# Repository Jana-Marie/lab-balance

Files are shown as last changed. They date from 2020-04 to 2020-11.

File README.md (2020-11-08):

# lab-balance

This project aims to replace the electronics contained within a [cheap scale from AliExpress](https://aliexpress.com/item/33024586342.html) to archive a higher resolution and hackability. Furthermore I need a scale which does not turn off after 30 seconds of use!

The goal is not met so far, as the accuracy of the load cell is not sufficient for this task. It can be replaced with a higher end model.

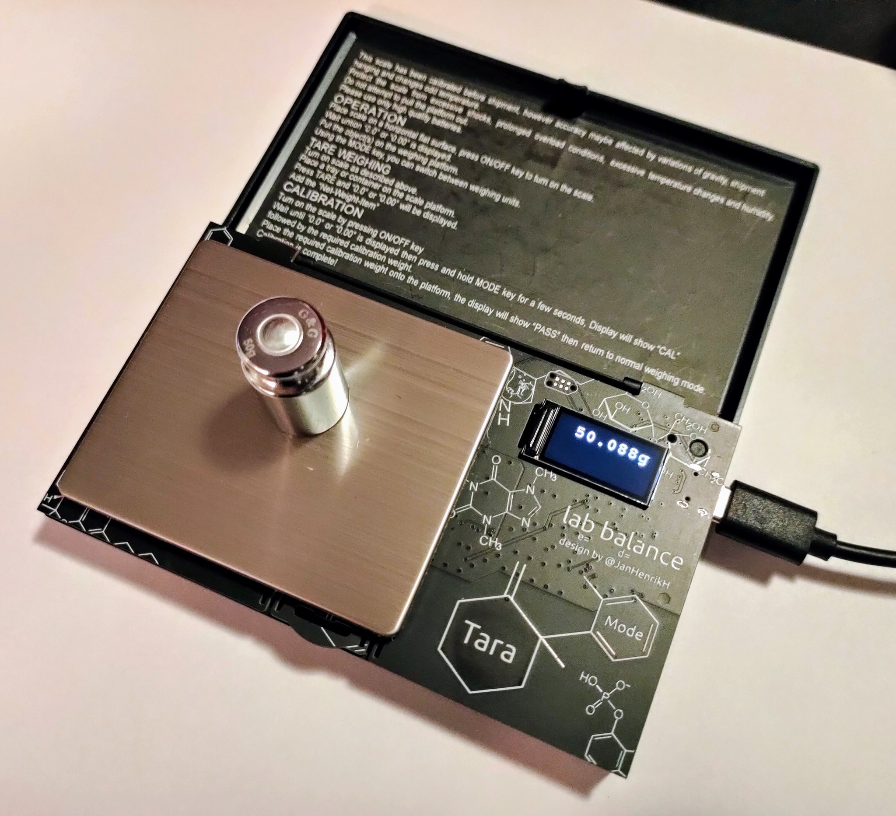
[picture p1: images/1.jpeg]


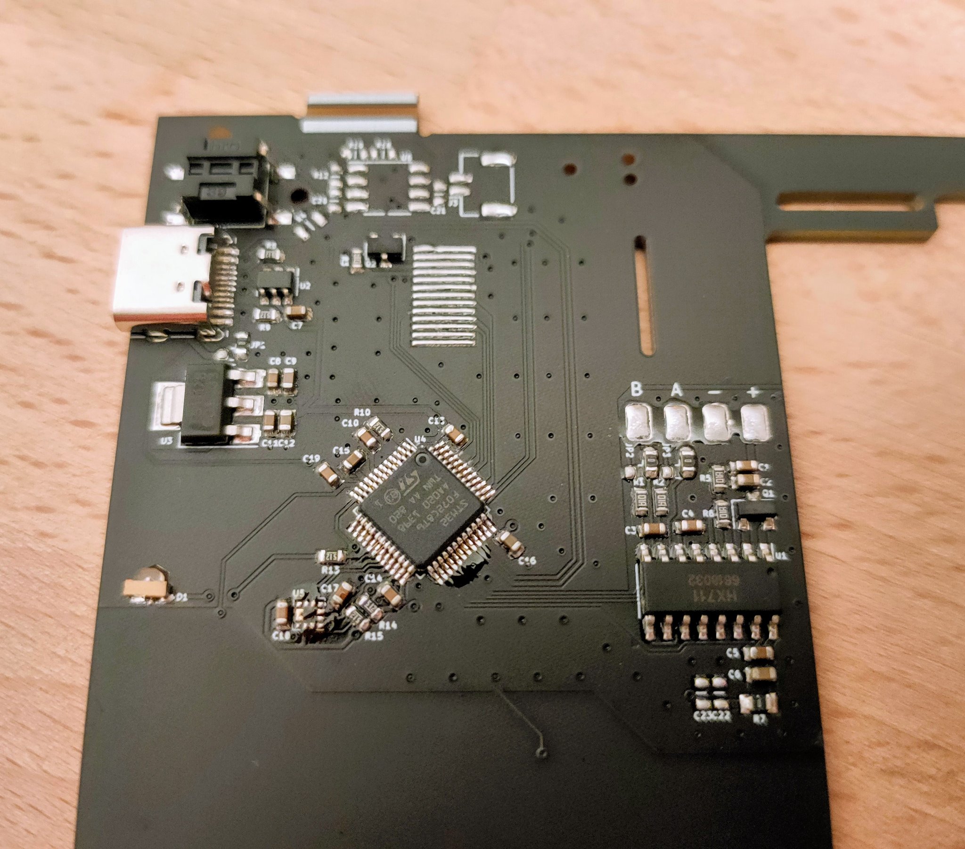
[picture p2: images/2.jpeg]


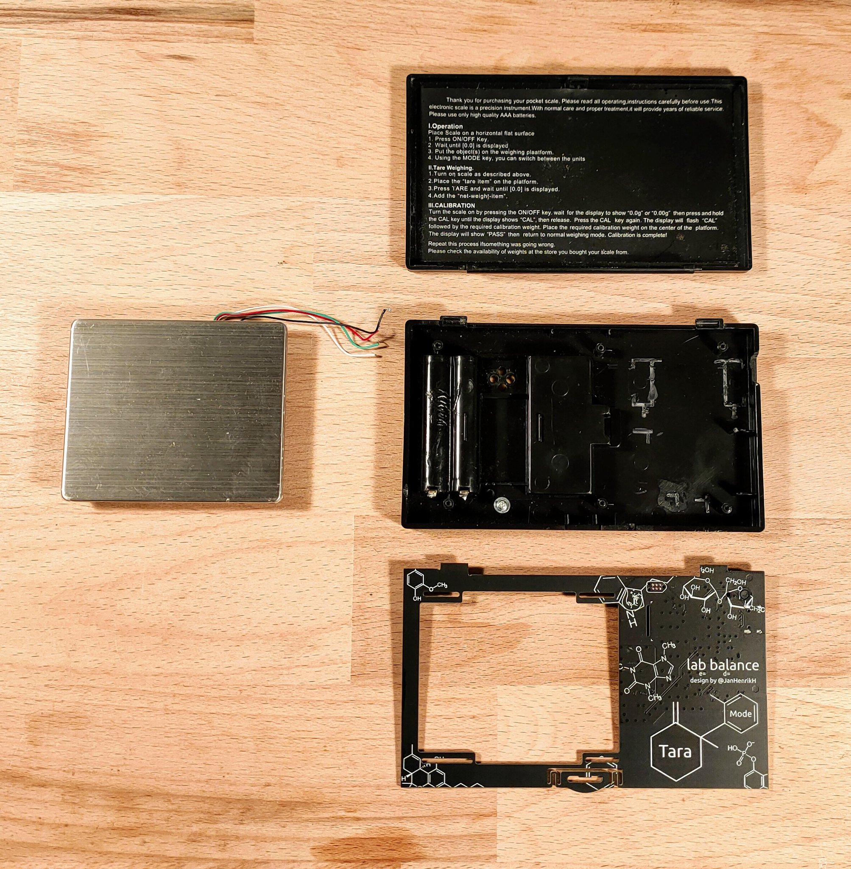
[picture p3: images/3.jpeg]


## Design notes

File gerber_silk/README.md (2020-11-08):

# note: There is a bug in the gerber files. The display has to be bodged in this version, order at your own risk!

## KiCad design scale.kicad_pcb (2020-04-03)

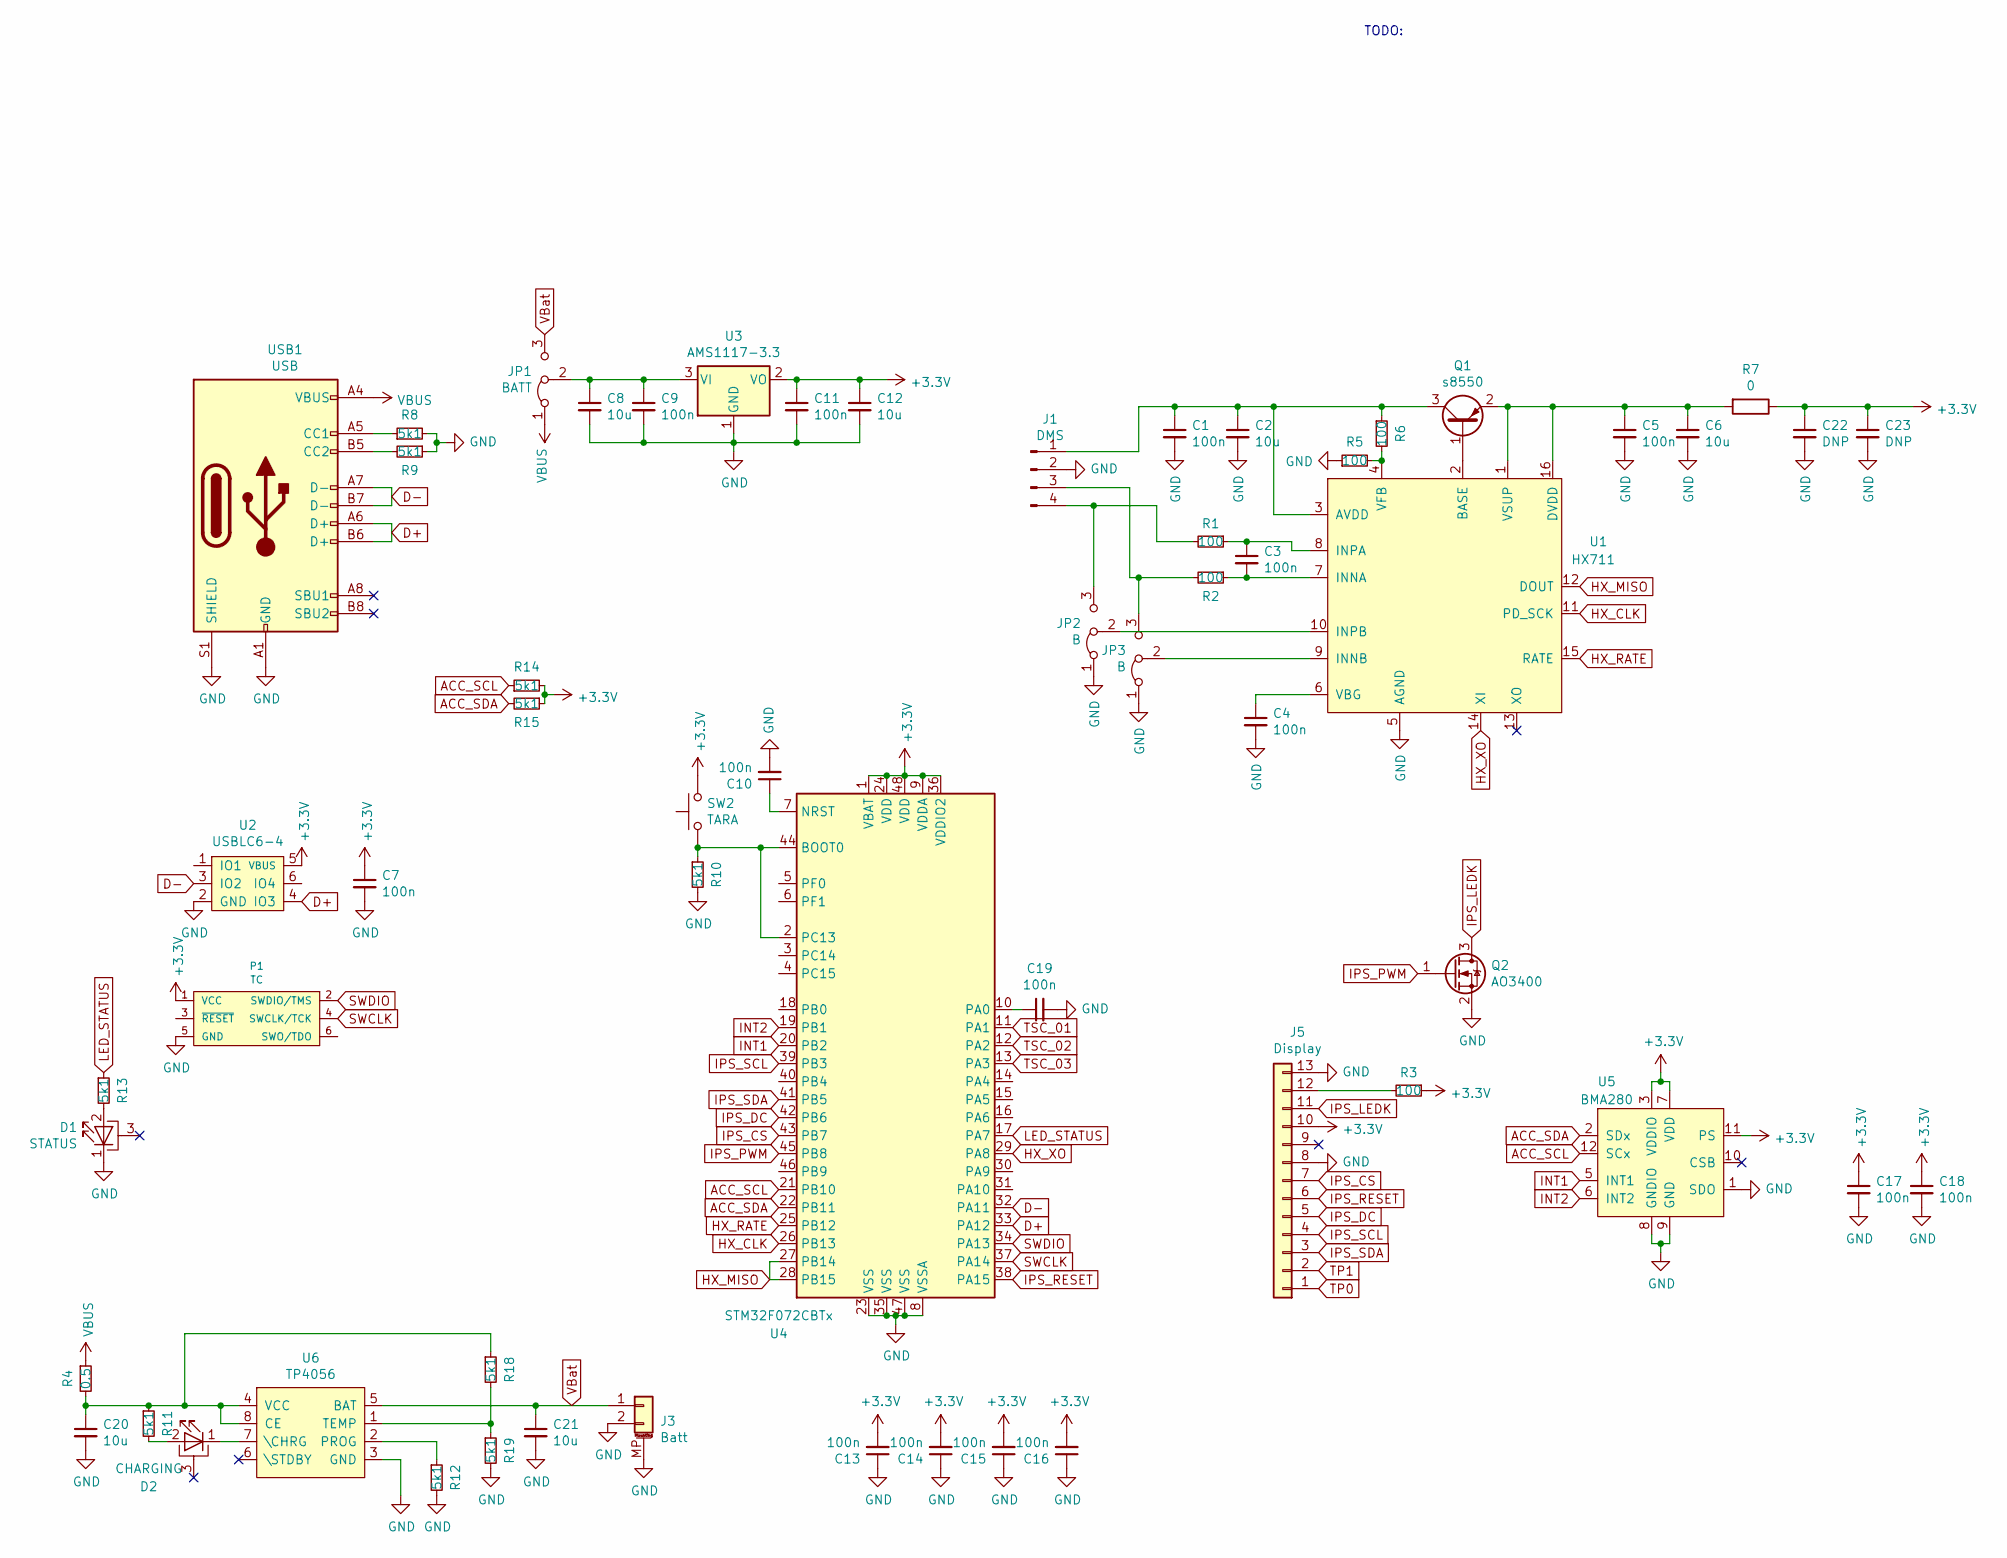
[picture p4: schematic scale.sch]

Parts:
C1, C3, C4, C5, C7, C9, C10, C11, C13, C14, C15, C16, C17, C18, C19: 100n; C_0603
C2, C6, C8, C12, C20, C21: 10u; C_0603
C22, C23: DNP; C_0603
D1: STATUS; BL-HUB34E-AV-TRB
D2: CHARGING; BL-HUB34E-AV-TRB
J1: DMS; 04_pads
J3: Batt; JST_GH_SM02B-GHS-TB_1x02-1MP_P1.25mm_Horizontal
J5: Display; 0.96IPS
JP1: BATT; J_0603_90
JP2, JP3: B; J_0603_90
P1: TC; TC2030
Q1: s8550; SOT-23
Q2: AO3400; SOT-23
R1, R2, R3, R5, R6: 100; R_0603
R4: 0.5; R_0805
R7: 0; R_0805
R8, R9, R10, R11, R12, R13, R14, R15, R18, R19: 5k1; R_0603
SW2: TARA; K2-1102DP-C4SW-04
U1: HX711; SOIC-16_3.9x9.9mm_P1.27mm
U2: USBLC6-4; SOT-23-6
U3: AMS1117-3.3; SOT-223-3_TabPin2
U4: STM32F072CBTx; LQFP-48_7x7mm_P0.5mm
U5: BMA280; LGA-12_2x2mm_P0.5mm
U6: TP4056; SOP-8_3.9x4.9mm_P1.27mm
USB1: USB; USB-C 16Pin

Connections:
+3V3: C7.1, C11.1, C12.1, C13.2, C14.2, C15.2, C16.2, C17.1, C18.1, C22.1, C23.1, J5.10, P1.1 (VCC), R3.1, R7.1, R14.2, R15.1, SW2.2, U2.5 (VBUS), U3.2 (VO), U4.1 (VBAT), U4.9 (VDDA), U4.24 (VDD), U4.36 (VDDIO2), U4.48 (VDD), U5.3 (VDDIO), U5.7 (VDD), U5.11 (PS)
ACC_SCL: R14.1, U4.21 (PB10), U5.12 (SCx)
ACC_SDA: R15.2, U4.22 (PB11), U5.2 (SDx)
D+: U2.4 (IO3), U4.33 (PA12), USB1.A6 (D+), USB1.B6 (D+)
D-: U2.3 (IO2), U4.32 (PA11), USB1.A7 (D-), USB1.B7 (D-)
GND: C1.2, C2.2, C4.2, C5.2, C6.2, C7.2, C8.2, C9.2, C10.2, C11.2, C12.2, C13.1, C14.1, C15.1, C16.1, C17.2, C18.2, C19.2, C20.2, C21.2, C22.2, C23.2, D1.1 (K), J1.2, J3.2, J3.MP (MountPin), J5.8, J5.13, JP2.1 (A), JP3.1 (A), P1.5 (GND), Q2.2 (S), R5.1, R8.2, R9.1, R10.2, R12.2, R19.2, U1.5 (AGND), U2.2 (GND), U3.1 (GND), U4.8 (VSSA), U4.23 (VSS), U4.35 (VSS), U4.47 (VSS), U5.1 (SDO), U5.8 (GNDIO), U5.9 (GND), U6.3 (GND), USB1.A1 (GND), USB1.A12 (GND), USB1.B1 (GND), USB1.B12 (GND), USB1.S1 (SHIELD)
HX_CLK: U1.11 (PD_SCK), U4.26 (PB13)
HX_MISO: U1.12 (DOUT), U4.27 (PB14), U4.28 (PB15)
HX_RATE: U1.15 (RATE), U4.25 (PB12)
HX_XO: U1.14 (XI), U4.29 (PA8)
INT1: U4.20 (PB2), U5.5 (INT1)
INT2: U4.19 (PB1), U5.6 (INT2)
IPS_CS: J5.7, U4.43 (PB7)
IPS_DC: J5.5, U4.42 (PB6)
IPS_LEDK: J5.11, Q2.3 (D)
IPS_PWM: Q2.1 (G), U4.45 (PB8)
IPS_RESET: J5.6, U4.38 (PA15)
IPS_SCL: J5.4, U4.39 (PB3)
IPS_SDA: J5.3, U4.41 (PB5)
LED_STATUS: R13.1, U4.17 (PA7)
unnamed: C1.1, C2.1, J1.1, Q1.3 (C), R6.1, U1.3 (AVDD)
unnamed: C3.1, R1.1, U1.8 (INPA)
unnamed: C3.2, R2.1, U1.7 (INNA)
unnamed: C4.1, U1.6 (VBG)
unnamed: C5.1, C6.1, Q1.2 (E), R7.2, U1.1 (VSUP), U1.16 (DVDD)
unnamed: C8.1, C9.1, JP1.2 (C), U3.3 (VI)
unnamed: C10.1, U4.7 (NRST)
unnamed: C19.1, U4.10 (PA0)
unnamed: C20.1, R4.2, R11.1, R18.1, U6.4 (VCC), U6.8 (CE)
unnamed: D1.2 (A), R13.2
unnamed: D2.1 (K), U6.7 (\CHRG)
unnamed: D2.2 (A), R11.2
unnamed: J1.3, JP3.3 (B), R2.2
unnamed: J1.4, JP2.3 (B), R1.2
unnamed: J5.12, R3.2
unnamed: JP2.2 (C), U1.10 (INPB)
unnamed: JP3.2 (C), U1.9 (INNB)
unnamed: Q1.1 (B), U1.2 (BASE)
unnamed: R5.2, R6.2, U1.4 (VFB)
unnamed: R8.1, USB1.A5 (CC1)
unnamed: R9.2, USB1.B5 (CC2)
unnamed: R10.1, SW2.1, U4.2 (PC13), U4.44 (BOOT0)
unnamed: R12.1, U6.2 (PROG)
unnamed: R18.2, R19.1, U6.1 (TEMP)
SWCLK: P1.4 (SWCLK/TCK), U4.37 (PA14)
SWDIO: P1.2 (SWDIO/TMS), U4.34 (PA13)
TP0: J5.1
TP1: J5.2
TSC_01: U4.11 (PA1)
TSC_02: U4.12 (PA2)
TSC_03: U4.13 (PA3)
VBUS: JP1.1 (A), R4.1, USB1.A4 (VBUS), USB1.A9 (VBUS), USB1.B4 (VBUS), USB1.B9 (VBUS)
VBat: C21.1, J3.1, JP1.3 (B), U6.5 (BAT)

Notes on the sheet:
TODO:

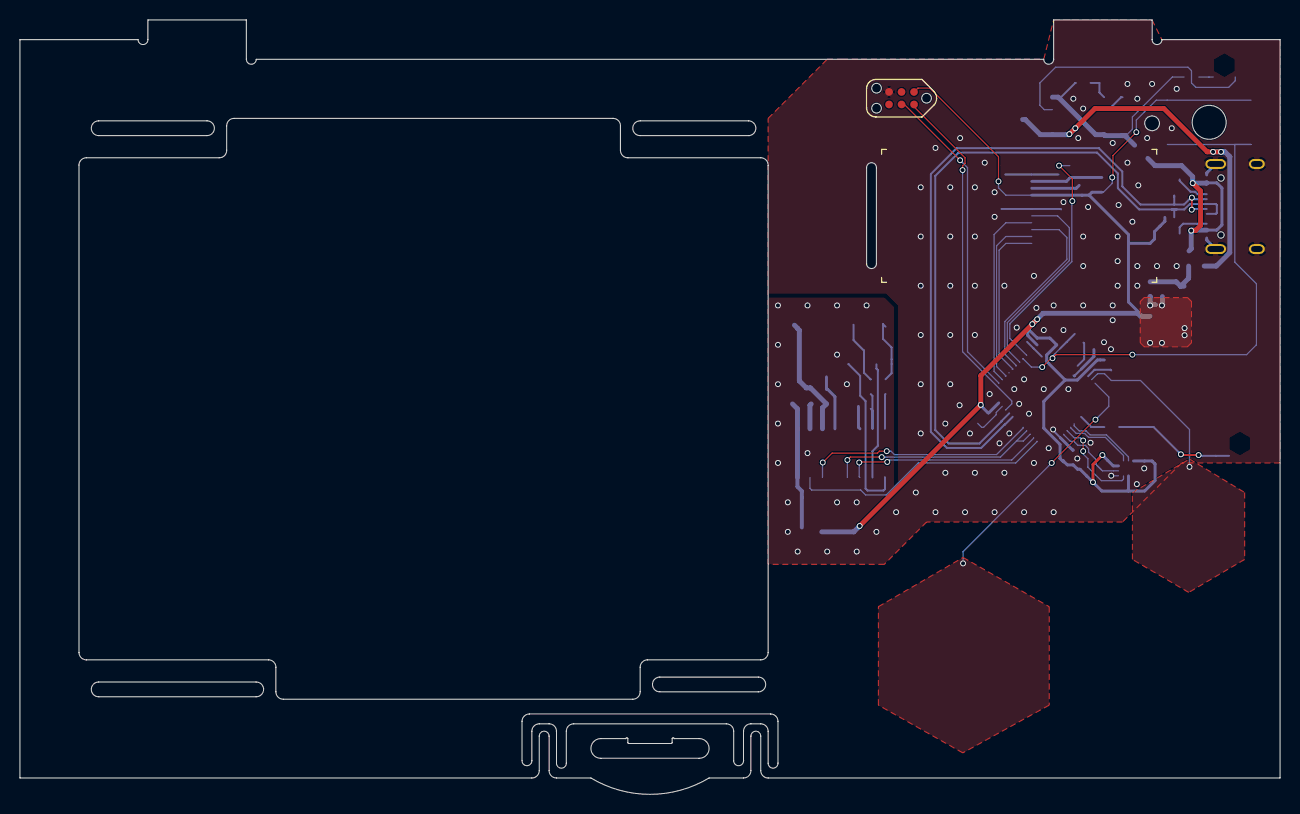
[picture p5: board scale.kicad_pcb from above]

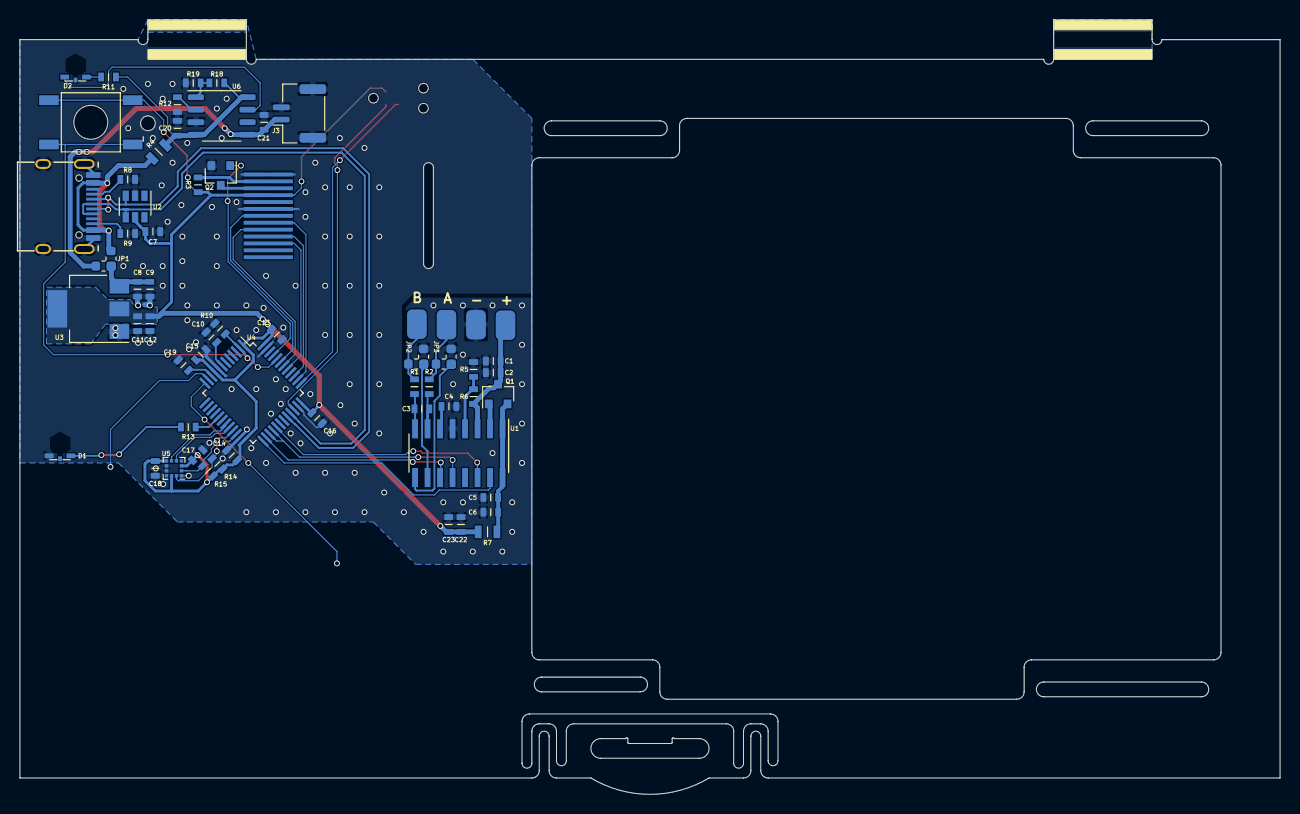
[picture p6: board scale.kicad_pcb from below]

Board: 2 copper layers, 128.0 x 78.7 mm, 59 parts (57 on the bottom side), 48 nets.

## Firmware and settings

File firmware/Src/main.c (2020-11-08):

#include "main.h"
#include "graphics.h"
#include "math.h"
#include "stdlib.h"
#include <stdio.h>
#include "image_header.h"

//#define ENABLE_CAL
//#define ENABLESERIAL

#define HX_GAIN_128 25
#define HX_GAIN_64  27
#define HX_GAIN_32  26
#define MULTIPLIER (72000000/4000000)

#define DATAFILT 0.99f

#define FLASH_ADDR 0x0800e400

I2C_HandleTypeDef hi2c2;

SPI_HandleTypeDef hspi1;
DMA_HandleTypeDef hdma_spi1_tx;

TIM_HandleTypeDef htim1;
TIM_HandleTypeDef htim16;
TIM_HandleTypeDef htim3;

TSC_HandleTypeDef htsc;
TSC_IOConfigTypeDef IoConfig;

USBD_HandleTypeDef USBD_Device;

void SystemClock_Config(void);
static void MX_GPIO_Init(void);
static void MX_DMA_Init(void);
static void MX_I2C2_Init(void);
static void MX_SPI1_Init(void);
static void MX_TIM1_Init(void);
static void MX_TIM16_Init(void);
static void MX_TSC_Init(void);
static void TIM3_Init();

void HX_Get_Value(uint8_t gain);
void HX_Delay(uint32_t u);
void write_tara_bar(uint8_t pos);
void clear_tara_bar(void);
void write_cal_flash(float cal);
void USB_printfloat(float _buf);

struct HX711_t{
  int32_t raw_data;
  int32_t raw_data_avg;
  int32_t delta;
  float weight_g;
  int32_t pcs;
  uint8_t gain;
  uint8_t rate;
  uint8_t clock;
  uint8_t is_stable;
} HX711 = {.gain = HX_GAIN_128};

struct cal_t{
  float g_50;
  float g_0;
  float g_cal;
  uint8_t tara_active;
  uint8_t tara_pcs_active;
  float pcs_cal;
} cal = {.g_cal = 50.093f, .g_50 = -701550.0f, .g_0 = -138500.0f, .tara_active = 1, .pcs_cal = 1.0f};
//50.093

struct touch_t{
  uint8_t button[2];
  uint16_t offset[2];
  uint16_t value[2];
  uint8_t idx_bank;
  uint8_t mode;
  uint8_t new_mode;
} t = {.new_mode = 1};

extern struct IPS_t IPS;

uint32_t start = 0;
uint32_t _ms;

extern uint8_t UserTxBuffer[APP_TX_DATA_SIZE];/* Received Data over UART (CDC interface) are stored in this buffer */
uint32_t sendDataUSB;

int main(void)
{
  HAL_Init();
  SystemClock_Config();

  MX_GPIO_Init();
  MX_DMA_Init();
  MX_I2C2_Init();
  MX_SPI1_Init();
  MX_TIM1_Init();
  MX_TIM16_Init();
  MX_TSC_Init();
  TIM3_Init();

  HAL_GPIO_WritePin(GPIOB,HX_CLK_Pin,0);

  IPS.backlight = 999;
  IPS.update_time = 20;

  #ifdef ENABLE_CAL
  cal.g_50 = *((float *) FLASH_ADDR);
  #endif

  IPS_Init();
  HAL_TIM_Base_Start(&htim16);
  HAL_TIM_PWM_Start(&htim16, TIM_CHANNEL_1);
  __HAL_TIM_SET_COMPARE(&htim16, TIM_CHANNEL_1, IPS.backlight);
  IPS_Clear(BLACK);
  IPS.update = HAL_GetTick();

  HAL_TSC_Start_IT(&htsc);

  HAL_TIM_Base_Start(&htim1);
  HAL_TIM_PWM_Start(&htim1, TIM_CHANNEL_1);
  __HAL_TIM_SET_COMPARE(&htim1, TIM_CHANNEL_1, 0);

  #ifdef ENABLESERIAL
      //start USB CDC
      USBD_Init(&USBD_Device, &VCP_Desc, 0);
      USBD_RegisterClass(&USBD_Device, &USBD_CDC);
      USBD_CDC_RegisterInterface(&USBD_Device, &USBD_CDC_fops);
      HAL_TIM_Base_Start_IT(&htim3);
      USBD_Start(&USBD_Device);
  #endif

  while (1)
  {
    if(t.button[1]) {
      cal.tara_active = 1;
      uint8_t cnt = 0;
      while (t.button[1]){
        if(cnt < 200) cnt++;
        HAL_Delay(2);
      }
      if(cnt >= 200){
        if(t.mode == 2){
        #ifdef ENABLE_CAL
          write_cal_flash(cal.g_50);
          HAL_NVIC_SystemReset();
        #endif
        } else {
         cal.tara_pcs_active = 1;
        }
      cal.tara_active = 0;
      }
    }

    if(t.button[0]) {
      while(t.button[0]) {
        HAL_Delay(1);
      }
      t.mode++;
      t.mode = t.mode % 3;
      t.new_mode = 1;
    }

    if(cal.tara_active && t.mode != 2){
      if(abs(HX711.delta) < 30) cal.tara_active++;
      else cal.tara_active = 1;
      write_tara_bar(cal.tara_active);
      if(cal.tara_active > 20){
        cal.g_0 = HX711.raw_data_avg;
        cal.tara_active = 0;
        clear_tara_bar();
      }
    } else if(cal.tara_active && t.mode == 2){
      if(abs(HX711.delta) < 30) cal.tara_active++;
      else cal.tara_active = 1;
      write_tara_bar(cal.tara_active);
      if(cal.tara_active > 20) {
        cal.g_50 = HX711.raw_data_avg;
        cal.tara_active = 0;
        clear_tara_bar();
      }
    }

    if (cal.tara_pcs_active){
      cal.pcs_cal = HX711.weight_g;
      cal.tara_pcs_active = 0;
      for(int i = 0; i <= 20; i++){
        write_tara_bar(i);
      }
      clear_tara_bar();
    }

    if(!HAL_GPIO_ReadPin(GPIOB,HX_INT_Pin)){
      HX_Get_Value(HX711.gain);
      HAL_GPIO_TogglePin(GPIOA, LED_Pin);
      _ms = HAL_GetTick()-start;
      start = HAL_GetTick();

      if(abs(HX711.delta) <= 2 && (int)((HX711.weight_g-(int)HX711.weight_g)*1000.0f) == 0){
        cal.g_0 -= HX711.delta;
      } else if(abs(HX711.delta) <= 2) {
        cal.g_0 -= HX711.delta;
        cal.g_50 -= HX711.delta;
      }

    } else {
      HAL_Delay(1);
      HAL_GPIO_WritePin(GPIOB,HX_SPS_Pin, HX711.rate);
    }

    if(HAL_GetTick() + IPS.update_time > IPS.update){
      if(HX711.weight_g > -99.9 && HX711.weight_g < 99.9){
        if(t.mode == 0){
          sprintf(IPS.buf,"%c%02d.%03dg", HX711.weight_g >= -0.001 ? ' ' : '-' , abs((int)HX711.weight_g), abs((int)((HX711.weight_g-(int)HX711.weight_g)*1000.0f)));
          IPS_DrawString_Buf(0, 0, IPS.buf, 8, &Font24, BLACK, WHITE);
          IPS_WriteBuf(10,45);
        } else if (t.mode == 1){
          sprintf(IPS.buf,"%c%04dpcs", HX711.weight_g >= -0.001 ? ' ' : '-' , abs((int)roundf(HX711.weight_g / cal.pcs_cal)));
          IPS_DrawString_Buf(0, 0, IPS.buf, 8, &Font24, BLACK, WHITE);
          IPS_WriteBuf(10,45);
        } else if (t.mode == 2){
          sprintf(IPS.buf,"%07d", HX711.raw_data_avg);
          IPS_DrawString_Buf(0, 0, IPS.buf, 8, &Font24, BLACK, WHITE);
          IPS_WriteBuf(10,45);
        }
      } else {
        sprintf(IPS.buf,"  max!  ");
        IPS_DrawString_Buf(0, 0, IPS.buf, 8, &Font24, BLACK, WHITE);
        IPS_WriteBuf(10,45);
      }
      HAL_Delay(4);
      if(t.new_mode == 1){
        if      (t.mode == 0) IPS_WriteBitmap(5 , 5, gram, 32, 20);
        else if (t.mode == 1) IPS_WriteBitmap(5 , 5, cnt, 32, 20);
        else if (t.mode == 2) IPS_WriteBitmap(5 , 5, cal_n, 32, 20);
        t.new_mode = 0;
      } else {
        IPS_WriteBitmap(116, 8, HX711.is_stable == 1 ? tara_green : tara_red, 32, 20);
      }
      IPS.update = HAL_GetTick();
    }
    #ifdef ENABLESERIAL
      // send temperature via USB CDC
      USB_printfloat(HX711.weight_g);
    #endif
  }
}

/* ~~~~~~~~~~~~~~~~~~~~~~~~~~~~~~~~~~~~~~~~~~~~~~~~~~~~~~~~~~~~~~~~~~~~~~~~~~~*/

void HX_Get_Value(uint8_t gain) {

  int32_t last_data = HX711.raw_data_avg;
  HX711.raw_data = 0;

  for(int i = 0; i < gain; i++){
    HAL_GPIO_WritePin(GPIOB,HX_CLK_Pin,1);
    HX_Delay(2);
    HAL_GPIO_WritePin(GPIOB,HX_CLK_Pin,0);
    if(i < 24){
      HX711.raw_data |= (HAL_GPIO_ReadPin(GPIOB,HX_DATA_Pin) << (24 - i));
    }
    if (HX711.raw_data & 0x00800000) HX711.raw_data |= 0xFF000000 ;
    HX_Delay(2);
  }

  if(abs(HX711.delta) > 1000) {
    HX711.rate = 1;
    HX711.raw_data_avg = HX711.raw_data;
    HX711.is_stable = 0;
    __HAL_TIM_SET_COMPARE(&htim1, TIM_CHANNEL_1, 0);
  }
  else if(abs(HX711.delta) > 20) {
    HX711.rate = 0;
    HX711.raw_data_avg = HX711.raw_data;
    HX711.is_stable = 0;
    __HAL_TIM_SET_COMPARE(&htim1, TIM_CHANNEL_1, 0);
  }
  else {
    HX711.rate = 0;
    HX711.is_stable = 1;
    __HAL_TIM_SET_COMPARE(&htim1, TIM_CHANNEL_1, 50);
  }


  HX711.raw_data_avg = (HX711.raw_data_avg * DATAFILT + (HX711.raw_data * (1.0f - DATAFILT)));
  HX711.delta = last_data - HX711.raw_data_avg;
  HX711.weight_g = (cal.g_cal*((HX711.raw_data_avg-cal.g_0)/(cal.g_50-cal.g_0)));
}

void HX_Delay(uint32_t u) {
    u = u * MULTIPLIER - 10;
    while (u--);
}

/* ~~~~~~~~~~~~~~~~~~~~~~~~~~~~~~~~~~~~~~~~~~~~~~~~~~~~~~~~~~~~~~~~~~~~~~~~~~~*/

void TSC_task(void) {
  if (HAL_TSC_GroupGetStatus(&htsc, TSC_GROUP1_IDX) == TSC_GROUP_COMPLETED) {
    t.value[t.idx_bank] = HAL_TSC_GroupGetValue(&htsc, TSC_GROUP1_IDX);
    HAL_TSC_IOConfig(&htsc, &IoConfig);
    HAL_TSC_IODischarge(&htsc, ENABLE);
    __HAL_TSC_CLEAR_FLAG(&htsc, (TSC_FLAG_EOA | TSC_FLAG_MCE));
    HAL_TSC_Start_IT(&htsc);
    if(t.value[t.idx_bank] < 3000) t.button[t.idx_bank] = 1;
    else t.button[t.idx_bank] = 0;
  }


  switch (t.idx_bank)
  {
  case 0:
    IoConfig.ChannelIOs = TSC_GROUP1_IO2;
    t.idx_bank = 1;
    break;
  case 1:
    IoConfig.ChannelIOs = TSC_GROUP1_IO3;
    t.idx_bank = 0;
    break;
  default:
    break;
  }
}
/* ~~~~~~~~~~~~~~~~~~~~~~~~~~~~~~~~~~~~~~~~~~~~~~~~~~~~~~~~~~~~~~~~~~~~~~~~~~~*/

void write_tara_bar(uint8_t pos){
  HAL_Delay(4);
  IPS_WriteBitmap(97 - (pos*2), 5, bar, 2, 20);
  HAL_Delay(1);
}

/* ~~~~~~~~~~~~~~~~~~~~~~~~~~~~~~~~~~~~~~~~~~~~~~~~~~~~~~~~~~~~~~~~~~~~~~~~~~~*/

void clear_tara_bar(){
  HAL_Delay(4);
  for(int i = 0; i <= 5; i++){
    IPS_WriteBitmap(97 - (i*9), 5, bb, 10, 20);
    HAL_Delay(1);
  }
}

/* ~~~~~~~~~~~~~~~~~~~~~~~~~~~~~~~~~~~~~~~~~~~~~~~~~~~~~~~~~~~~~~~~~~~~~~~~~~~*/

void write_cal_flash(float cal){
  HAL_FLASH_Unlock();
  FLASH->CR |= FLASH_CR_PER;
  FLASH->AR = FLASH_ADDR;
  FLASH->CR |= FLASH_CR_STRT;
  while ((FLASH->SR & FLASH_SR_BSY) != 0){}
  if ((FLASH->SR & FLASH_SR_EOP) != 0){
    FLASH->SR |= FLASH_SR_EOP;
    FLASH->CR &= ~FLASH_CR_PER;
    HAL_FLASH_Program(FLASH_TYPEPROGRAM_DOUBLEWORD, FLASH_ADDR, cal);
    HAL_FLASH_Lock();
  }
}

/* ~~~~~~~~~~~~~~~~~~~~~~~~~~~~~~~~~~~~~~~~~~~~~~~~~~~~~~~~~~~~~~~~~~~~~~~~~~~*/

#ifdef ENABLESERIAL
void USB_printfloat(float _buf){
  memset(UserTxBuffer, 0, APP_TX_DATA_SIZE);
  sprintf(UserTxBuffer, "%02d.%04d \r\n", (uint16_t)_buf,(uint16_t)((_buf-(uint16_t)_buf)*1000.0f));
  sendDataUSB = 1;
}
#endif

/* ~~~~~~~~~~~~~~~~~~~~~~~~~~~~~~~~~~~~~~~~~~~~~~~~~~~~~~~~~~~~~~~~~~~~~~~~~~~*/

void HAL_TIM_PeriodElapsedCallback(TIM_HandleTypeDef *htim) //send USB cdc data
{
  if(sendDataUSB) // WIP need to fix this, should me timer based only
  {
    sendDataUSB = 0;

    USBD_CDC_SetTxBuffer(&USBD_Device, (uint8_t*)&UserTxBuffer[0], APP_TX_DATA_SIZE);
    USBD_CDC_TransmitPacket(&USBD_Device);
  }
}

/* ~~~~~~~~~~~~~~~~~~~~~~~~~~~~~~~~~~~~~~~~~~~~~~~~~~~~~~~~~~~~~~~~~~~~~~~~~~~*/

void SystemClock_Config(void)
{
  RCC_OscInitTypeDef RCC_OscInitStruct = {0};
  RCC_ClkInitTypeDef RCC_ClkInitStruct = {0};
  RCC_PeriphCLKInitTypeDef PeriphClkInit = {0};

  RCC_OscInitStruct.OscillatorType = RCC_OSCILLATORTYPE_HSI48;
  RCC_OscInitStruct.HSI48State = RCC_HSI48_ON;
  RCC_OscInitStruct.PLL.PLLState = RCC_PLL_NONE;
  HAL_RCC_OscConfig(&RCC_OscInitStruct);

  RCC_ClkInitStruct.ClockType = RCC_CLOCKTYPE_HCLK|RCC_CLOCKTYPE_SYSCLK
                              |RCC_CLOCKTYPE_PCLK1;
  RCC_ClkInitStruct.SYSCLKSource = RCC_SYSCLKSOURCE_HSI48;
  RCC_ClkInitStruct.AHBCLKDivider = RCC_SYSCLK_DIV1;
  RCC_ClkInitStruct.APB1CLKDivider = RCC_HCLK_DIV1;
  HAL_RCC_ClockConfig(&RCC_ClkInitStruct, FLASH_LATENCY_1);

  PeriphClkInit.PeriphClockSelection = RCC_PERIPHCLK_USB;
  PeriphClkInit.UsbClockSelection = RCC_USBCLKSOURCE_HSI48;
  HAL_RCCEx_PeriphCLKConfig(&PeriphClkInit);
}

static void MX_I2C2_Init(void)
{
  hi2c2.Instance = I2C2;
  hi2c2.Init.Timing = 0x20303E5D;
  hi2c2.Init.OwnAddress1 = 0;
  hi2c2.Init.AddressingMode = I2C_ADDRESSINGMODE_7BIT;
  hi2c2.Init.DualAddressMode = I2C_DUALADDRESS_DISABLE;
  hi2c2.Init.OwnAddress2 = 0;
  hi2c2.Init.OwnAddress2Masks = I2C_OA2_NOMASK;
  hi2c2.Init.GeneralCallMode = I2C_GENERALCALL_DISABLE;
  hi2c2.Init.NoStretchMode = I2C_NOSTRETCH_DISABLE;
  HAL_I2C_Init(&hi2c2);
  HAL_I2CEx_ConfigAnalogFilter(&hi2c2, I2C_ANALOGFILTER_ENABLE);
  HAL_I2CEx_ConfigDigitalFilter(&hi2c2, 0);
}

static void MX_SPI1_Init(void)
{
  hspi1.Instance = SPI1;
  hspi1.Init.Mode = SPI_MODE_MASTER;
  hspi1.Init.Direction = SPI_DIRECTION_2LINES;
  hspi1.Init.DataSize = SPI_DATASIZE_8BIT;
  hspi1.Init.CLKPolarity = SPI_POLARITY_LOW;
  hspi1.Init.CLKPhase = SPI_PHASE_1EDGE;
  hspi1.Init.NSS = SPI_NSS_SOFT;
  hspi1.Init.BaudRatePrescaler = SPI_BAUDRATEPRESCALER_2;
  hspi1.Init.FirstBit = SPI_FIRSTBIT_MSB;
  hspi1.Init.TIMode = SPI_TIMODE_DISABLE;
  hspi1.Init.CRCCalculation = SPI_CRCCALCULATION_DISABLE;
  hspi1.Init.CRCPolynomial = 7;
  hspi1.Init.CRCLength = SPI_CRC_LENGTH_DATASIZE;
  hspi1.Init.NSSPMode = SPI_NSS_PULSE_ENABLE;
  HAL_SPI_Init(&hspi1);
}

static void MX_TIM1_Init(void)
{
  TIM_ClockConfigTypeDef sClockSourceConfig = {0};
  TIM_MasterConfigTypeDef sMasterConfig = {0};
  TIM_OC_InitTypeDef sConfigOC = {0};
  TIM_BreakDeadTimeConfigTypeDef sBreakDeadTimeConfig = {0};

  htim1.Instance = TIM1;
  htim1.Init.Prescaler = 0;
  htim1.Init.CounterMode = TIM_COUNTERMODE_UP;
  htim1.Init.Period = 10;
  htim1.Init.ClockDivision = TIM_CLOCKDIVISION_DIV1;
  htim1.Init.RepetitionCounter = 0;
  htim1.Init.AutoReloadPreload = TIM_AUTORELOAD_PRELOAD_DISABLE;
  HAL_TIM_Base_Init(&htim1);

  sClockSourceConfig.ClockSource = TIM_CLOCKSOURCE_INTERNAL;
  HAL_TIM_ConfigClockSource(&htim1, &sClockSourceConfig);
  HAL_TIM_PWM_Init(&htim1);

  sMasterConfig.MasterOutputTrigger = TIM_TRGO_RESET;
  sMasterConfig.MasterSlaveMode = TIM_MASTERSLAVEMODE_DISABLE;
  HAL_TIMEx_MasterConfigSynchronization(&htim1, &sMasterConfig);

  sConfigOC.OCMode = TIM_OCMODE_PWM1;
  sConfigOC.Pulse = 50;
  sConfigOC.OCPolarity = TIM_OCPOLARITY_HIGH;
  sConfigOC.OCNPolarity = TIM_OCNPOLARITY_HIGH;
  sConfigOC.OCFastMode = TIM_OCFAST_DISABLE;
  sConfigOC.OCIdleState = TIM_OCIDLESTATE_RESET;
  sConfigOC.OCNIdleState = TIM_OCNIDLESTATE_RESET;
  HAL_TIM_PWM_ConfigChannel(&htim1, &sConfigOC, TIM_CHANNEL_1);

  sBreakDeadTimeConfig.OffStateRunMode = TIM_OSSR_DISABLE;
  sBreakDeadTimeConfig.OffStateIDLEMode = TIM_OSSI_DISABLE;
  sBreakDeadTimeConfig.LockLevel = TIM_LOCKLEVEL_OFF;
  sBreakDeadTimeConfig.DeadTime = 0;
  sBreakDeadTimeConfig.BreakState = TIM_BREAK_DISABLE;
  sBreakDeadTimeConfig.BreakPolarity = TIM_BREAKPOLARITY_HIGH;
  sBreakDeadTimeConfig.AutomaticOutput = TIM_AUTOMATICOUTPUT_DISABLE;
  HAL_TIMEx_ConfigBreakDeadTime(&htim1, &sBreakDeadTimeConfig);
  HAL_TIM_MspPostInit(&htim1);
}


static void TIM3_Init(void)
{
  __HAL_RCC_TIM3_CLK_ENABLE();
  TIM_ClockConfigTypeDef sClockSourceConfig = {0};

  /*
       + Period = 10000 - 1
       + Prescaler = ((8000000/2)/10000) - 1

  */
  htim3.Instance = TIM3;
  htim3.Init.Period = (CDC_POLLING_INTERVAL*1000) - 1;
  htim3.Init.Prescaler = 399;
  htim3.Init.ClockDivision = 0;
  htim3.Init.CounterMode = TIM_COUNTERMODE_UP;
  htim3.Init.AutoReloadPreload = TIM_AUTORELOAD_PRELOAD_DISABLE;
  if(HAL_TIM_Base_Init(&htim3) != HAL_OK)
  {
    /* Initialization Error */
    Error_Handler();
  }
  sClockSourceConfig.ClockSource = TIM_CLOCKSOURCE_INTERNAL;
  HAL_TIM_ConfigClockSource(&htim3, &sClockSourceConfig);
}


static void MX_TIM16_Init(void)
{
  TIM_OC_InitTypeDef sConfigOC = {0};
  TIM_BreakDeadTimeConfigTypeDef sBreakDeadTimeConfig = {0};

  htim16.Instance = TIM16;
  htim16.Init.Prescaler = 10;
  htim16.Init.CounterMode = TIM_COUNTERMODE_UP;
  htim16.Init.Period = 1000;
  htim16.Init.ClockDivision = TIM_CLOCKDIVISION_DIV1;
  htim16.Init.RepetitionCounter = 0;
  htim16.Init.AutoReloadPreload = TIM_AUTORELOAD_PRELOAD_ENABLE;
  HAL_TIM_Base_Init(&htim16);
  HAL_TIM_PWM_Init(&htim16);

  sConfigOC.OCMode = TIM_OCMODE_PWM1;
  sConfigOC.Pulse = 100;
  sConfigOC.OCPolarity = TIM_OCPOLARITY_HIGH;
  sConfigOC.OCNPolarity = TIM_OCNPOLARITY_HIGH;
  sConfigOC.OCFastMode = TIM_OCFAST_DISABLE;
  sConfigOC.OCIdleState = TIM_OCIDLESTATE_RESET;
  sConfigOC.OCNIdleState = TIM_OCNIDLESTATE_RESET;
  HAL_TIM_PWM_ConfigChannel(&htim16, &sConfigOC, TIM_CHANNEL_1);

  sBreakDeadTimeConfig.OffStateRunMode = TIM_OSSR_DISABLE;
  sBreakDeadTimeConfig.OffStateIDLEMode = TIM_OSSI_DISABLE;
  sBreakDeadTimeConfig.LockLevel = TIM_LOCKLEVEL_OFF;
  sBreakDeadTimeConfig.DeadTime = 0;
  sBreakDeadTimeConfig.BreakState = TIM_BREAK_DISABLE;
  sBreakDeadTimeConfig.BreakPolarity = TIM_BREAKPOLARITY_HIGH;
  sBreakDeadTimeConfig.AutomaticOutput = TIM_AUTOMATICOUTPUT_DISABLE;
  HAL_TIMEx_ConfigBreakDeadTime(&htim16, &sBreakDeadTimeConfig);
  HAL_TIM_MspPostInit(&htim16);
}

static void MX_TSC_Init(void)
{

  htsc.Instance = TSC;
  htsc.Init.CTPulseHighLength = TSC_CTPH_1CYCLE;
  htsc.Init.CTPulseLowLength = TSC_CTPL_1CYCLE;
  htsc.Init.SpreadSpectrum = ENABLE;
  htsc.Init.SpreadSpectrumDeviation = 32;
  htsc.Init.SpreadSpectrumPrescaler = TSC_SS_PRESC_DIV1;
  htsc.Init.PulseGeneratorPrescaler = TSC_PG_PRESC_DIV4;
  htsc.Init.MaxCountValue = TSC_MCV_16383;
  htsc.Init.IODefaultMode = TSC_IODEF_OUT_PP_LOW;
  htsc.Init.SynchroPinPolarity = TSC_SYNC_POLARITY_FALLING;
  htsc.Init.AcquisitionMode = TSC_ACQ_MODE_NORMAL;
  htsc.Init.MaxCountInterrupt = DISABLE;
  htsc.Init.ChannelIOs = TSC_GROUP1_IO2|TSC_GROUP1_IO3;
  htsc.Init.ShieldIOs = 0;
  htsc.Init.SamplingIOs = TSC_GROUP1_IO1;
  HAL_TSC_Init(&htsc);

  IoConfig.ChannelIOs  = TSC_GROUP1_IO2; // Start with the first channel
  IoConfig.SamplingIOs = TSC_GROUP1_IO1;
  IoConfig.ShieldIOs   = 0;
  HAL_TSC_IOConfig(&htsc, &IoConfig);

}

static void MX_DMA_Init(void)
{

  __HAL_RCC_DMA1_CLK_ENABLE();

  HAL_NVIC_SetPriority(DMA1_Channel2_3_IRQn, 0, 0);
  HAL_NVIC_EnableIRQ(DMA1_Channel2_3_IRQn);

  HAL_NVIC_SetPriority(TIM3_IRQn, 0, 0);
  HAL_NVIC_EnableIRQ(TIM3_IRQn);
}

static void MX_GPIO_Init(void)
{
  GPIO_InitTypeDef GPIO_InitStruct = {0};

  __HAL_RCC_GPIOC_CLK_ENABLE();
  __HAL_RCC_GPIOA_CLK_ENABLE();
  __HAL_RCC_GPIOB_CLK_ENABLE();

  HAL_GPIO_WritePin(GPIOA, LED_Pin|IPS_RESET_Pin, GPIO_PIN_RESET);
  HAL_GPIO_WritePin(GPIOB, HX_SPS_Pin|HX_CLK_Pin|IPS_DC_Pin|IPS_CS_Pin, GPIO_PIN_RESET);

  GPIO_InitStruct.Pin = DFU_Pin;
  GPIO_InitStruct.Mode = GPIO_MODE_INPUT;
  GPIO_InitStruct.Pull = GPIO_NOPULL;
  HAL_GPIO_Init(DFU_GPIO_Port, &GPIO_InitStruct);

  GPIO_InitStruct.Pin = LED_Pin|IPS_RESET_Pin;
  GPIO_InitStruct.Mode = GPIO_MODE_OUTPUT_PP;
  GPIO_InitStruct.Pull = GPIO_NOPULL;
  GPIO_InitStruct.Speed = GPIO_SPEED_FREQ_LOW;
  HAL_GPIO_Init(GPIOA, &GPIO_InitStruct);

  GPIO_InitStruct.Pin = ACC_INT1_Pin|ACC_INT2_Pin|HX_INT_Pin;
  GPIO_InitStruct.Mode = GPIO_MODE_IT_RISING;
  GPIO_InitStruct.Pull = GPIO_NOPULL;
  HAL_GPIO_Init(GPIOB, &GPIO_InitStruct);

  GPIO_InitStruct.Pin = HX_SPS_Pin|HX_CLK_Pin|IPS_DC_Pin|IPS_CS_Pin;
  GPIO_InitStruct.Mode = GPIO_MODE_OUTPUT_PP;
  GPIO_InitStruct.Pull = GPIO_NOPULL;
  GPIO_InitStruct.Speed = GPIO_SPEED_FREQ_LOW;
  HAL_GPIO_Init(GPIOB, &GPIO_InitStruct);

  GPIO_InitStruct.Pin = HX_DATA_Pin;
  GPIO_InitStruct.Mode = GPIO_MODE_INPUT;
  GPIO_InitStruct.Pull = GPIO_NOPULL;
  HAL_GPIO_Init(HX_DATA_GPIO_Port, &GPIO_InitStruct);
}

void Error_Handler(){
  while(1){
    HAL_GPIO_TogglePin(GPIOA, LED_Pin);
    HAL_Delay(100);
  }
}

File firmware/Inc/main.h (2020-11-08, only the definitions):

#define DFU_Pin GPIO_PIN_13
#define DFU_GPIO_Port GPIOC
#define LED_Pin GPIO_PIN_7
#define LED_GPIO_Port GPIOA
#define ACC_INT1_Pin GPIO_PIN_1
#define ACC_INT1_GPIO_Port GPIOB
#define ACC_INT2_Pin GPIO_PIN_2
#define ACC_INT2_GPIO_Port GPIOB
#define ACC_SCL_Pin GPIO_PIN_10
#define ACC_SCL_GPIO_Port GPIOB
#define ACC_SDA_Pin GPIO_PIN_11
#define ACC_SDA_GPIO_Port GPIOB
#define HX_SPS_Pin GPIO_PIN_12
#define HX_SPS_GPIO_Port GPIOB
#define HX_CLK_Pin GPIO_PIN_13
#define HX_CLK_GPIO_Port GPIOB
#define HX_DATA_Pin GPIO_PIN_14
#define HX_DATA_GPIO_Port GPIOB
#define HX_INT_Pin GPIO_PIN_15
#define HX_INT_GPIO_Port GPIOB
#define IPS_RESET_Pin GPIO_PIN_15
#define IPS_RESET_GPIO_Port GPIOA
#define IPS_SCK_Pin GPIO_PIN_3
#define IPS_SCK_GPIO_Port GPIOB
#define IPS_MOSI_Pin GPIO_PIN_5
#define IPS_MOSI_GPIO_Port GPIOB
#define IPS_DC_Pin GPIO_PIN_6
#define IPS_DC_GPIO_Port GPIOB
#define IPS_CS_Pin GPIO_PIN_7
#define IPS_CS_GPIO_Port GPIOB
#define IPS_PWM_Pin GPIO_PIN_8
#define IPS_PWM_GPIO_Port GPIOB

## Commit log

2020-03-02 added gerber
    [scale-B_Cu.gbl, scale-B_Mask.gbs, scale-B_Paste.gbp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]
2020-03-02 pushed latest files
    [scale-B_Cu.gbl, scale-B_Mask.gbs, scale-B_Paste.gbp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]
2020-06-07 calibrated load cell

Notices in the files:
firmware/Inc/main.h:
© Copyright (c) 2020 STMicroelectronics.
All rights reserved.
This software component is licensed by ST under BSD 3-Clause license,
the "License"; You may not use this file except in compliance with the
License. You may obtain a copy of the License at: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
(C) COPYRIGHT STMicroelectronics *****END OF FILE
